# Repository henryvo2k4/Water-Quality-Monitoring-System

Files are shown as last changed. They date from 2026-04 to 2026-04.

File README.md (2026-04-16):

# 💧 Smart Water Quality Monitoring System (IoT)

 

*Note: This project was developed as part of an educational mentoring program for hardware engineering students.*

---

## 🇬🇧 English Version

A comprehensive IoT system designed to monitor real-time water quality across 5 critical parameters. The system utilizes a dual-microcontroller architecture: an Arduino Uno acts as the dedicated sensor data acquisition node, which processes analog signals and transmits them via UART to an ESP8266. The ESP8266 hosts a dynamic local Web Dashboard to visualize the data.

### 🚀 Key Technical Features
* **Dual-MCU Architecture:** Seamless UART serial communication between Arduino Uno (Sensor Node) and NodeMCU ESP8266 (WiFi/Web Node).
* **Multi-Parameter Sensing:** Real-time tracking of **pH, TDS (Total Dissolved Solids), Turbidity, DO (Dissolved Oxygen)**, and **Temperature** (DS18B20).
* **Advanced Signal Processing:** * Implements **Median Filtering** and **Moving Average** algorithms to eliminate ADC noise and stabilize analog readings.
  * Real-time **Temperature Compensation** applied to both TDS and Dissolved Oxygen algorithms for industrial-grade accuracy.
* **Dynamic Web Dashboard:** Hosts a sleek, responsive UI using Google Charts (`gauge` visualization). Automatically updates every second and alerts users to abnormal levels via color-coded indicators.
* **Captive Portal WiFi Config:** Features an embedded DNS server and EEPROM storage to seamlessly configure local WiFi credentials without hardcoding or re-flashing.

### 🛠️ Hardware Diagram

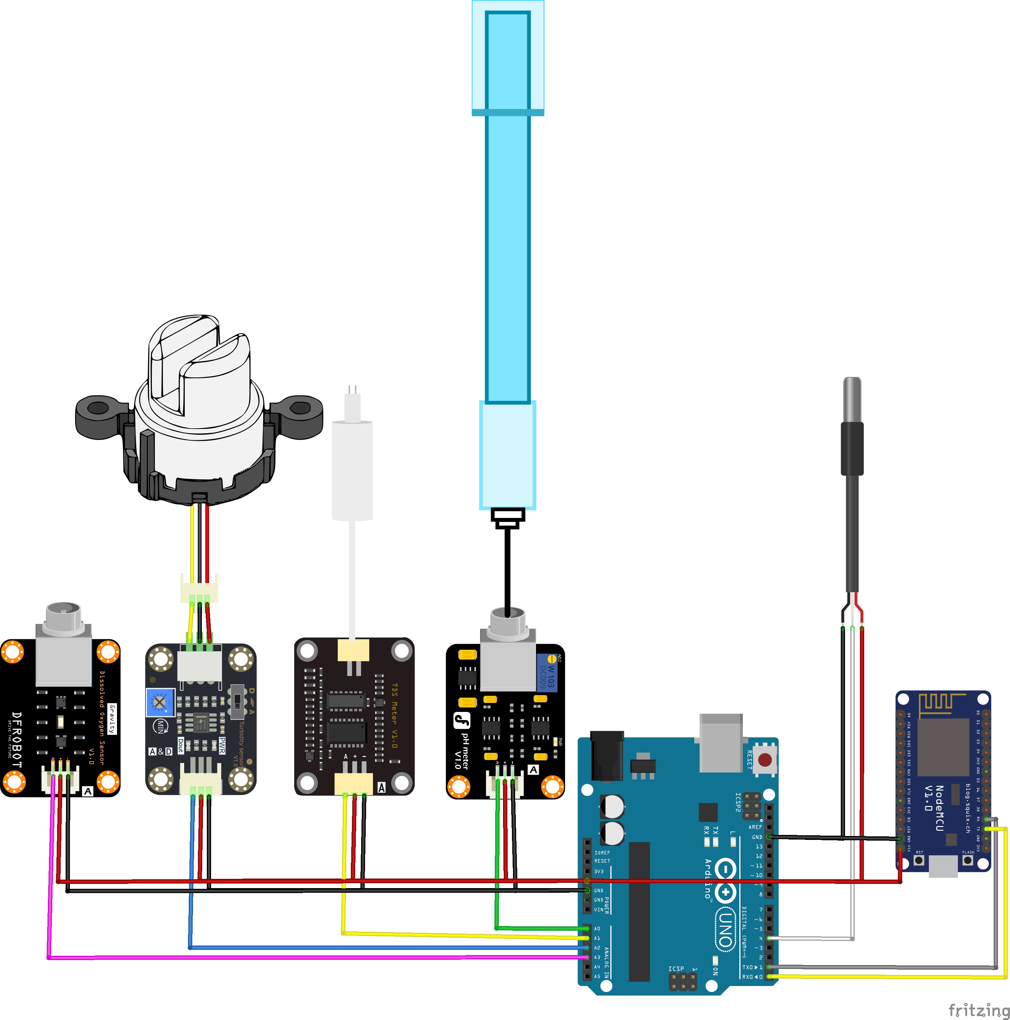
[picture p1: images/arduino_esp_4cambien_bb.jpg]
Water Quality Wiring Diagram

*(Note: Visualizes the intricate analog routing and UART connection between the microcontrollers).*

---

## 🇻🇳 Bản Tiếng Việt

Hệ thống IoT giám sát chất lượng nước toàn diện theo thời gian thực. Dự án ứng dụng kiến trúc vi điều khiển kép: Arduino Uno đóng vai trò Node thu thập và xử lý tín hiệu cảm biến, sau đó truyền dữ liệu qua giao thức UART sang ESP8266. ESP8266 chịu trách nhiệm duy trì kết nối mạng và khởi chạy một Web Server nội bộ trực quan.

### 🚀 Tính năng kỹ thuật nổi bật
* **Kiến trúc MCU Kép:** Giao tiếp nối tiếp (UART) đồng bộ giữa Arduino và ESP8266, tích hợp cơ chế kiểm tra trạng thái mất kết nối (UART timeout alert).
* **Đa cảm biến:** Đo lường đồng thời 5 chỉ số: **pH, TDS, Độ đục (Turbidity), Nồng độ Oxy hòa tan (DO)** và **Nhiệt độ** (DS18B20).
* **Xử lý Tín hiệu Số (DSP):** * Áp dụng thuật toán **Lọc trung vị (Median Filter)** và **Trung bình động (Moving Average)** để loại bỏ nhiễu tín hiệu ADC từ môi trường nước.
  * Tích hợp thuật toán **Bù nhiệt độ (Temperature Compensation)** vào phương trình tính toán TDS và DO, đảm bảo độ chính xác cao.
* **Web Dashboard Trực quan:** Giao diện điều khiển sử dụng Google Charts (Gauge), tự động cập nhật dữ liệu mỗi giây bằng Fetch API. Hiển thị cảnh báo trực quan (Xanh/Vàng/Đỏ) khi chỉ số vượt ngưỡng an toàn.
* **Cấu hình WiFi Thông minh (Captive Portal):** Tự động phát WiFi nội bộ để người dùng nhập mật khẩu mạng nhà. Lưu trữ cấu hình an toàn vào EEPROM của ESP8266.

### ⚙️ Hướng dẫn nạp code (Flashing Guide)
1. **Sensor Node:** Mở `Sensor_Node_Arduino/arduino_4cambien.ino`, nạp vào bo mạch Arduino Uno. (Yêu cầu thư viện: `OneWire`, `DallasTemperature`).
2. **Web Node:** Mở `Web_Server_ESP8266/esp01_4cambien.ino`. Chỉnh sửa lại các thông số IP Tĩnh (Static IP) nếu cần thiết cho phù hợp với Router của bạn, sau đó nạp vào ESP8266.

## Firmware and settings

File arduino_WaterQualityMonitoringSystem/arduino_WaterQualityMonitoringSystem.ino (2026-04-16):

#include <OneWire.h>
#include <DallasTemperature.h>

// ---------- Cảm biến pH -----------
#define PH_PIN A0
#define PH_OFFSET 0
#define PH_ARRAY_LENGTH 40
int pHArray[PH_ARRAY_LENGTH];
int pHIndex = 0;

// ---------- Cảm biến TDS ----------
#define TDS_PIN A1
#define VREF 5.0
#define TDS_SAMPLES 30
int tdsBuffer[TDS_SAMPLES];
int tdsIndex = 0;

// ---------- Cảm biến Độ đục (Turbidity) ----
#define TUR_PIN A2
#define TUR_SAMPLES 30
int turBuffer[TUR_SAMPLES];
int turIndex = 0;

// ---------- Cảm biến Nhiệt độ DS18B20 ------
#define ONE_WIRE_BUS 4
OneWire oneWire(ONE_WIRE_BUS);
DallasTemperature sensors(&oneWire);

// ---------- Cảm biến DO ----------
#define DO_PIN A3
#define DO_VREF 5000    // mV
#define ADC_RES 1024    // Độ phân giải ADC
#define TWO_POINT_CALIBRATION 0
#define CAL1_V 1600     // mV
#define CAL1_T 25       // °C
#define CAL2_V 1300     // mV
#define CAL2_T 15       // °C

const uint16_t DO_Table[41] = {
  14460, 14220, 13820, 13440, 13090, 12740, 12420, 12110, 11810, 11530,
  11260, 11010, 10770, 10530, 10300, 10080, 9860, 9660, 9460, 9270,
  9080, 8900, 8730, 8570, 8410, 8250, 8110, 7960, 7820, 7690,
  7560, 7430, 7300, 7180, 7070, 6950, 6840, 6730, 6630, 6530, 6410
};

int16_t readDO_raw(uint32_t voltage_mv, uint8_t temperature_c) {
#if TWO_POINT_CALIBRATION == 0
  uint16_t V_saturation = (uint32_t)CAL1_V + (uint32_t)35 * temperature_c - (uint32_t)CAL1_T * 35;
  return (voltage_mv * DO_Table[temperature_c] / V_saturation);
#else
  uint16_t V_saturation = (int16_t)((int8_t)temperature_c - CAL2_T) * ((uint16_t)CAL1_V - CAL2_V) / ((uint8_t)CAL1_T - CAL2_T) + CAL2_V;
  return (voltage_mv * DO_Table[temperature_c] / V_saturation);
#endif
}

void setup() {
  Serial.begin(9600);
  pinMode(TDS_PIN, INPUT);
  sensors.begin();
}

void loop() {
  // Lấy dữ liệu từ các cảm biến
  float currentTemp = readTemperature();
  float phValue = readPH();
  float tdsValue = readTDS(currentTemp);
  float turbValue = readTurbidity();
  
  // Đọc DO (raw: μg/L) và chuyển sang mg/L
  float doValue_mgL = readDO_raw(
      (uint32_t)DO_VREF * analogRead(DO_PIN) / ADC_RES,
      (uint8_t)currentTemp
  ) / 1000.0;

  // Gửi dữ liệu qua Serial dưới dạng chuỗi CSV
  Serial.print(currentTemp, 2);
  Serial.print(",");
  Serial.print(phValue, 2);
  Serial.print(",");
  Serial.print(tdsValue, 0);
  Serial.print(",");
  Serial.print(turbValue, 2);
  Serial.print(",");
  Serial.println(doValue_mgL, 2); 

  delay(100);
}

float readTemperature() {
  sensors.requestTemperatures();
  return sensors.getTempCByIndex(0);
}

float readPH() {
  pHArray[pHIndex++] = analogRead(PH_PIN);
  if (pHIndex == PH_ARRAY_LENGTH) pHIndex = 0;
  float pHVoltage = (averageArray(pHArray, PH_ARRAY_LENGTH) / 1024.0) * 5.0;
  return 3.50 * pHVoltage + PH_OFFSET;
}

float readTDS(float temperature) {
  tdsBuffer[tdsIndex++] = analogRead(TDS_PIN);
  if (tdsIndex >= TDS_SAMPLES) tdsIndex = 0;
  int tdsFiltered = medianFilter(tdsBuffer, TDS_SAMPLES);
  float voltage = (tdsFiltered / 1024.0) * VREF;
  float compensation = 1.0 + 0.02 * (temperature - 25.0);
  float compVoltage = voltage / compensation;
  return (133.42 * compVoltage * compVoltage * compVoltage
         - 255.86 * compVoltage * compVoltage
         + 857.39 * compVoltage) * 0.05;
}

float readTurbidity() {
  turBuffer[turIndex++] = analogRead(TUR_PIN);
  if (turIndex >= TUR_SAMPLES) turIndex = 0;
  float turVoltage = averageArray(turBuffer, TUR_SAMPLES) * 5.0 / 1024.0;
  float U0 = 3.44; 
  float f = turVoltage / U0;
  float turbValue = (1.0 - f) * 200;
  if (turbValue < 0) turbValue = 0;
  return turbValue;
  // return turVoltage;
}

// Hàm tính trung bình, bỏ qua giá trị min và max
float averageArray(int* arr, int size) {
  if (size <= 2) return 0;
  long sum = 0;
  int maxVal = arr[0];
  int minVal = arr[0];
  for (int i = 0; i < size; i++) {
    if (arr[i] > maxVal) maxVal = arr[i];
    if (arr[i] < minVal) minVal = arr[i];
    sum += arr[i];
  }
  sum = sum - maxVal - minVal;
  return (float)sum / (size - 2);
}

// Hàm lọc trung vị
int medianFilter(int *arr, int len) {
  int sorted[len];
  memcpy(sorted, arr, sizeof(int) * len);
  for (int i = 0; i < len - 1; i++) {
    for (int j = 0; j < len - i - 1; j++) {
      if (sorted[j] > sorted[j + 1]) {
        int temp = sorted[j];
        sorted[j] = sorted[j + 1];
        sorted[j + 1] = temp;
      }
    }
  }
  if (len % 2 == 0)
    return (sorted[len / 2 - 1] + sorted[len / 2]) / 2;
  else
    return sorted[len / 2];
}

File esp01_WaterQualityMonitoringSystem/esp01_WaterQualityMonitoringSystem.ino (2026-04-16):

#include <ESP8266WiFi.h>
#include <ESP8266WebServer.h>
#include <EEPROM.h>
#include "index.h"
#include "wifi_config.h"

#define EEPROM_SIZE 96

bool uartActive = false;
unsigned long lastUartTime = 0;


// Wi-Fi mặc định trong code
const char* hardcoded_ssid = "American Study //HD";
const char* hardcoded_pass = "66668888";

// Thông tin AP mặc định khi không kết nối được Wi-Fi đã lưu
const char* my_default_ssid = "ESP01_AQM";
const char* my_default_pass = "12345678";

// IP tĩnh khi chạy ở chế độ AP
IPAddress local_IP(192, 168, 1, 177);
IPAddress gateway(192, 168, 1, 1);
IPAddress subnet(255, 255, 255, 0);
IPAddress primaryDNS(8, 8, 8, 8);
IPAddress secondaryDNS(8, 8, 4, 4);

ESP8266WebServer server(80);

float tempValue = 0, phValue = 0, tdsValue = 0, turbValue = 0, doValue = 0;
bool dataReceived = false;
unsigned long lastDataTime = 0;
const unsigned long dataTimeout = 3000;

String storedSSID = "";
String storedPASS = "";

void saveWiFiConfig(String ssid, String pass) {
  EEPROM.begin(EEPROM_SIZE);
  for (int i = 0; i < 32; i++) EEPROM.write(i, (i < ssid.length()) ? ssid[i] : 0);
  EEPROM.write(31, 0); // đảm bảo chuỗi kết thúc
  for (int i = 0; i < 64; i++) EEPROM.write(32 + i, (i < pass.length()) ? pass[i] : 0);
  EEPROM.write(95, 0); // đảm bảo chuỗi kết thúc
  EEPROM.commit();
}


void loadWiFiConfig() {
  EEPROM.begin(EEPROM_SIZE);
  char ssid[33], pass[65];
  for (int i = 0; i < 32; i++) ssid[i] = EEPROM.read(i);
  for (int i = 0; i < 64; i++) pass[i] = EEPROM.read(32 + i);
  ssid[32] = 0;
  pass[64] = 0;
  storedSSID = String(ssid);
  storedPASS = String(pass);
}

bool connectWiFi(String ssid, String pass) {
  WiFi.disconnect(true);
  if (!WiFi.config(local_IP, gateway, subnet, primaryDNS, secondaryDNS)) {
    Serial.println("Lỗi cấu hình IP tĩnh");
  }
  WiFi.begin(ssid.c_str(), pass.c_str());
  Serial.printf("Đang kết nối tới Wi-Fi: %s\n", ssid.c_str());

  unsigned long start = millis();
  while (millis() - start < 20000) {
    if (WiFi.status() == WL_CONNECTED && WiFi.localIP() != IPAddress(0, 0, 0, 0)) {
      Serial.printf("Kết nối thành công! IP: %s\n", WiFi.localIP().toString().c_str());
      return true;
    }
    delay(500);
    Serial.print(".");
  }
  Serial.println("\nKết nối thất bại hoặc IP không hợp lệ.");
  return false;
}

void startAPConfig() {
  // IP cho chế độ AP → phải cùng lớp mạng 192.168.4.x
  IPAddress apIP(192, 168, 4, 1);
  IPAddress apGateway(192, 168, 4, 1);
  IPAddress apSubnet(255, 255, 255, 0);

  WiFi.mode(WIFI_AP);
  WiFi.softAPConfig(apIP, apGateway, apSubnet);
  WiFi.softAP(my_default_ssid, my_default_pass);

  Serial.printf("Chế độ AP Config. Kết nối tới SSID: %s, Pass: %s\n", 
                my_default_ssid, my_default_pass);
  Serial.printf("IP: %s\n", WiFi.softAPIP().toString().c_str());

    // Trang config Wi-Fi
  server.on("/", []() {
    server.send(200, "text/html", configPage);
  });

  // API quét Wi-Fi
  server.on("/scanwifi", []() {
    int n = WiFi.scanNetworks();
    String json = "[";
    for (int i = 0; i < n; i++) {
      if (i) json += ",";
      json += "\"" + WiFi.SSID(i) + "\"";
    }
    json += "]";
    server.send(200, "application/json", json);
  });

  // API lưu Wi-Fi
  server.on("/savewifi", []() {
    if (server.hasArg("ssid") && server.hasArg("pass")) {
      saveWiFiConfig(server.arg("ssid"), server.arg("pass"));
      server.send(200, "text/plain", "Lưu thành công. ESP sẽ khởi động lại.");
      delay(1000);
      ESP.restart();
    } else {
      server.send(400, "text/plain", "Thiếu tham số");
    }
  });
}


void setup() {
  Serial.begin(9600);
  loadWiFiConfig();

  bool connected = false;

  // 1. Thử Wi-Fi lưu trong EEPROM
  if (storedSSID.length() > 0) {
    connected = connectWiFi(storedSSID, storedPASS);
  }

  // 2. Nếu không được, thử Wi-Fi mặc định hard-code
  if (!connected) {
    connected = connectWiFi(hardcoded_ssid, hardcoded_pass);
  }

  // 3. Nếu vẫn không được → phát AP config
  if (!connected) {
    startAPConfig();
  }

  // API realtime
  server.on("/data", []() {
    String json = "{";
    json += "\"ph\":" + String(phValue, 2) + ",";
    json += "\"tds\":" + String(tdsValue, 0) + ",";
    json += "\"temp\":" + String(tempValue, 1) + ",";
    json += "\"turb\":" + String(turbValue, 2) + ",";
    json += "\"do\":" + String(doValue, 2) + ",";
    json += "\"uart\":" + String(uartActive ? 1 : 0);
    json += "}";
    server.send(200, "application/json", json);
  });

    // Trang chính
  server.on("/", []() {
    String html = MAIN_page;
    html.replace("%PH%", String(phValue, 2));
    html.replace("%TDS%", String(tdsValue, 0));
    html.replace("%TEMP%", String(tempValue, 1));
    html.replace("%TURB%", String(turbValue, 2));
    html.replace("%DO%", String(doValue, 2));
    server.send(200, "text/html", html);
  });

  server.begin();
  Serial.println("HTTP server started");
}

void loop() {
  server.handleClient();
  readSerialData();
  if (millis() - lastDataTime > dataTimeout) {
    dataReceived = false;
  }
}

void readSerialData() {
  if (Serial.available()) {
    String line = Serial.readStringUntil('\n');
    lastUartTime = millis();
uartActive = true;

    line.trim();
    if (line.length() > 0) {
      float values[5] = { 0 };
      int idx = 0;
      int lastComma = 0;
      for (int i = 0; i < line.length(); i++) {
        if (line.charAt(i) == ',' || i == line.length() - 1) {
          String val = line.substring(lastComma, (i == line.length() - 1) ? i + 1 : i);
          val.trim();
          values[idx++] = val.toFloat();
          lastComma = i + 1;
          if (idx >= 5) break;
        }
      }
      if (idx == 5) {
        tempValue = values[0];
        phValue = values[1];
        tdsValue = values[2];
        turbValue = values[3];
        doValue = values[4];
        dataReceived = true;
        lastDataTime = millis();
        Serial.printf("Updated -> Temp: %.2f, pH: %.2f, TDS: %.0f, Turb: %.2f\n, DO: %.2f\n",
                      tempValue, phValue, tdsValue, turbValue, doValue);
      }
    }
  }
  if (millis() - lastUartTime > 5000) {
  uartActive = false;
}

}
